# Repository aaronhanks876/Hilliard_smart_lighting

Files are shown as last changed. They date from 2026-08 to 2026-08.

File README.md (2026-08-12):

# Hilliard Smart Lighting 
   
## Rasperry PI IP address:
192.168.60.6
## MQTT Usernames and Passwords
### RGB boxes:
n = the number of the box   
Username: RGBn  
Password: HilliardRGB#n
### AC boxes:
Username: ACn  
Password: HilliardAC#n
### Node-RED Broker
Username: Node-RED  
Password: HilliardNode-RED
### Music Processing
Username: MusicBox  
Password: HilliardMusicBox

## Other Usernames and Passwords
### Node-RED Admin Account
Username: intern  
Password: Nut-3nact-D3pict!
### Node-RED UI/User Account
Username: Hilliard  
Password: Sm3lls-Lik3-Sad!

# System Explanation  
Written here is a brief explanation of the flow of the system, followed by more in depth explanations of each individual part of the system.
The system works in 4 major steps:
1. Audio is played on a computer with a pyapp installed to run the music processing. The app reads the system audio and runs a fast fourier transform to seperate the audio into frequencies. The app can then analyze different frequency ranges (bass, treble, and mid) and send out a trigger when they cross a certain threshold (80%, for example).
2. The trigger signal is sent to the MQTT broker, and is redirected to Node-RED, which runs the user interface for lighting control
3. A lighting control signal determined by configuration in the user interface is sent to the broker by Node-RED, and is redirected to the individual lighting boxes.
4. The individual boxes receive their instructions and flash accordingly
## Music Processing
## MQTT
MQTT is the protocol used for the sending of control signals in the reactive lighting system.
### Topics
The different parts of the system are organized into various topics:
| **/lights** | **/lights/RGB** | **/lights/RGB/boxn** | **/lights/RGB/boxn/connection** | **/lights/RGB/brightness** | **/lights/RGB/speed** |
| :---: | :---: | :---: | :---: | :---: | :---: |
| Where trigger signals from the music processing are sent | An organizational topic | Where the light controls for each individual RGB box (of number n) are sent | Where connection and disconnection messages from each individual RGB box (of number n) are sent | Where brightness controls for RGB boxes are sent | Where speed controls for RGB boxes are sent |
| | **/lights/AC**  | **/lights/AC/boxn**  | **/lights/AC/boxn/connection**  | | |
| | An organizational topic | Where the light controls for each individual AC box (of number n) are sent | where connection and disconnection messages from each individual AC box (of number n) are sent | | |

### Broker
The MQTT broker is run by Mosquitto on a Raspberry PI 
### Node-RED
Node-RED provides configuration of the lights. It runs the user interface, which is hosted by a Raspberry PI alongside the code itself. The code menu can be accessed by entering the ip of the Raspberry PI alongside the 1880 port into the search bar: "(IP address):1880". The UI can be accessed by typing in the same address alongside "/ui": "(IP address):1880/ui"  
  
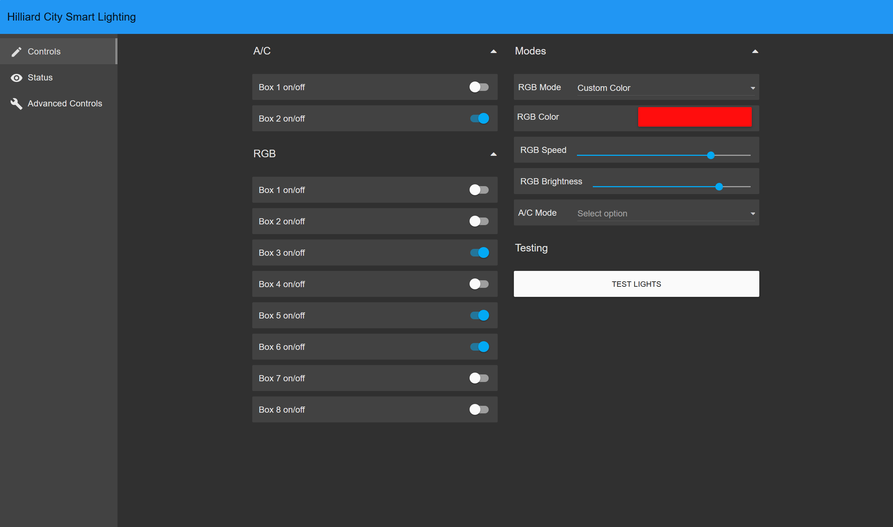
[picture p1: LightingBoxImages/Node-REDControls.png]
  
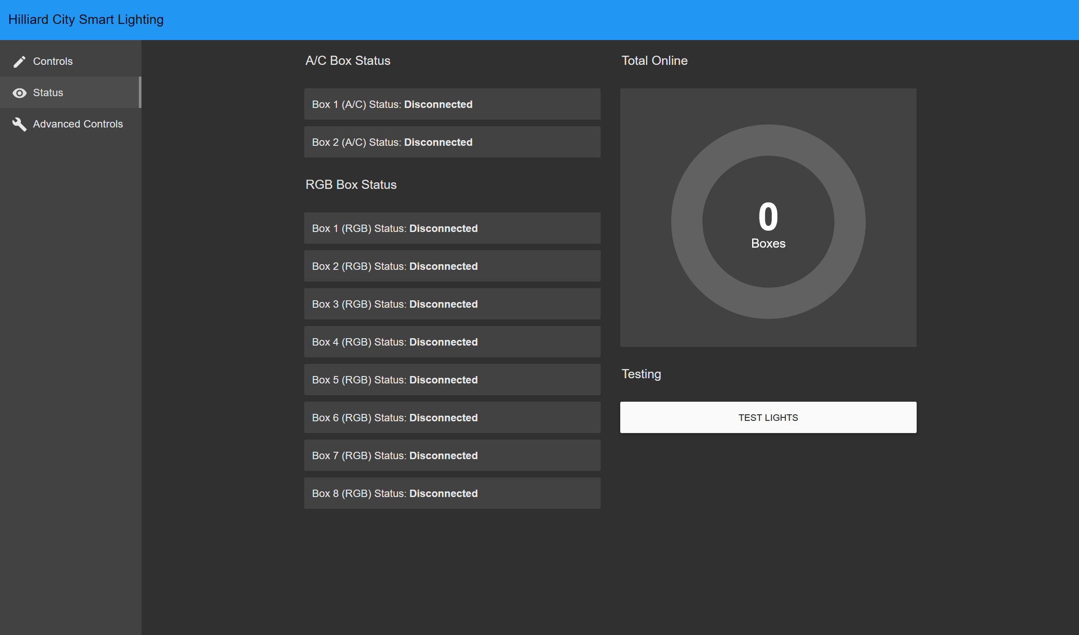
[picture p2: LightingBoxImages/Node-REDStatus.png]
  
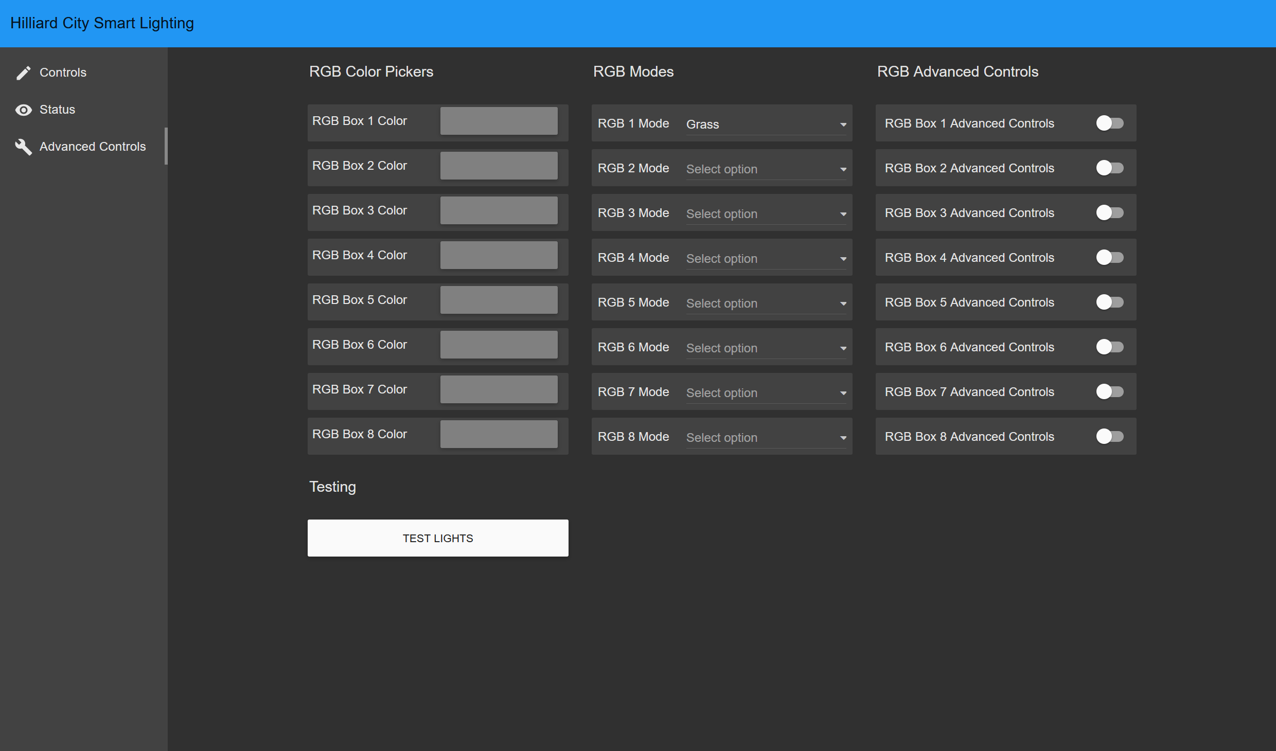
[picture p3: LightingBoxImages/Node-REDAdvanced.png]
  

#### Code Explanation
##### Overview
The Node-RED code works by receiving some input signal from the MQTT broker, sequentially checking all of the settings configured in the UI, and outputting the appropriate signal to send to the boxes. 
##### User Interface
The UI is built using the UIBUILDER Node-RED addon. Through these nodes the different options in the UI are configured. This includes the on/off toggles for all the boxes, the advanced mode toggles for the RGB boxes, the HSV color pickers, the mode selectors for all the boxes, the speed and brightness sliders for the RGB boxes, the test lights buttons, and the total boxes online display.
##### RGB 
- The bulk of the RGB code is checking the settings to see what should be sent to the different boxes. It works in eight phases to check for all of the settings:
  1. The code receives a trigger from an MQTT node (the contents of the signal do not matter)
  2. The code sets a variable "time" to the current UNIX time
  3. The code sets a "delayTime" variable to the sum of "time," and a "delay" variable. It then sets the message payload to a string of "mode " + delayTime.
  4. The message is sent to eight different switches (for eight different boxes), all of which check if their assigned box is turned on. 
  5. The message is sent through a switch which checks if advanced mode is turned on for the assigned box. It then sends the messages to either the regular mode, or advanced mode switches.
  6. Both regular and advanced mode switches check if the mode is set to custom. They then send to either the mode changer, or the custom color changer for their respective complexity.
  7. Both changers will change the "mode" part of the message payload into the mode set in the UI. The color changer will send an HSV value, and the mode will send a value from 1-5. If this is the advanced mode, it will be specific to that box. If it is regular mode, it will be the generalized mode.
  8. The resulting messages payload is sent to an MQTT node which publishes to the proper topic for their respective box.
- The RGB speed and brightness sliders both send the result directly onto their respective topics, which are read by the RGB boxes.
- The RGB connection works by setting the connection status when a given box sends a connection or disconnection message. 
##### AC
- The AC code is far simpler than the RGB code, because it does not have advanced controls to control the individual boxes. It works in five phases instead of eight.
  1. The code receives a trigger from an MQTT node (the contents of the signal do not matter)
  2. The trigger is sent to two different switches (one for each box), each of which checks if its assigned box is on
  3. The trigger is sent through a change node, and is changed into the number for the mode set in the UI
  4. The message is sent through a delay node, which delays it so that it will be in sync with the RGB boxes
  5. The message is sent to an MQTT node which publishes to the proper topic for its assigned box
- AC connection status works in the same way as RGB connection status
##### Broker
- The connection display works by giving each box a number variable for its connection. If it is connected, then it is a one, and if it is not connected, then it is a 0. All these variable are summed and displayed in a gauge in the user interface
- Test lights buttons work by using an MQTT node to send a signal to the same topic the music processing code sends signals on.
  
#### List of Utilities
- Controls
  - A/C
    - On/off control for A/C boxes
  - Modes
    - RGB Mode
      - Fire
      - Grass
      - Ocean
      - Rainbow
      - Christmas
      - Custom
    - RGB Color
      - A color picker, used alongside the "Custom" RGB mode to allow for the user to pick a custom color
    - RGB Speed
      - Used to choose the speed at which the RGB pulses travel
    - RGB Brightness
      - Used to choose the brightness of the RGB LEDs
    - A/C Mode
      - Twinkle
      - Flash
  - RGB
    - On/off control of RGB boxes
  - Testing
    - Has a button to send a test signal to the lights
- Status
  - A/C Box Status
    - Shows the connection status of all A/C boxes
  - RGB Box Status
    - Shows the connection status of all RGB boxes
  - Total Online
    - Has a dial that shows the amount of boxes that are online
  - Testing
    - Has a button to send a test signal to the lights
- Advanced Controls
  - RGB Color Pickers
    - HSV color pickers for each individual box
  - RGB Modes
    - Mode selectors for each individual box
  - RGB Advanced Controls
    - Toggles to turn on or off advanced controls for each individual box
  - Testing
    - Has a button to send a test signal to the lights
  
## RGB Lighting Control Boxes  
The RGB lighting control boxes (RGB boxes) are stored inside waterproof boxes, and comprised of one ESP32 microcontroller to run the code, a 5V power supply to power the ESP32, and an RGB connection cable.  
  
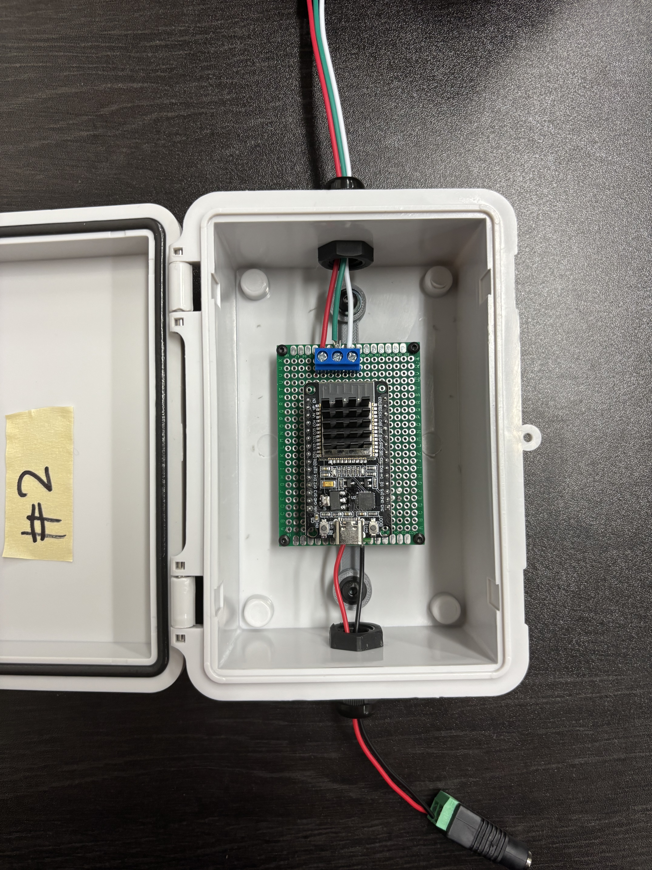
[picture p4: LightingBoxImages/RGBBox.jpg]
  

### ESP32 Code explanation

`setup()`
- Checks to see what protocol the lights follow (RGB or GRB)
- Calculates the center and end points (collision distances) of each pulse
- Sets all the LEDs to black
- Runs `connectToWifi()`
- Sets up the MQTT connection
- Syncs up the ESP's internal clock with time from pool.ntp.org.

`loop()` 
- Tries to reconnect to the server if the connection is lost
- Loops through mqtt_client_loop()
- Runs through `processDelays()` to push through the backlog
- Checks to see if the LEDs need to be updated based on the system clock.

`updateAnimations() `
- Runs the pulses, pushing the lit LED outwards until the collision distance

`drawPatterns()`
- Defines what each of the `colorModes` do (how they fade/change over the strip)

`spawnPulse()`
- Loops through all of `pulsePositions[]` and sets those that are equal to -1 (inactive) to the `targetColor`

`setLedSafe()` 
- Sets LEDs, but only when they actually exist, preventing errors

`Get_Epoch_Time` 
- Requests the current time from the internet to the second

`mqttCallback()` 
- Handles the incoming messages, and adds them to the backlog with their timestamp

`handleModeMessage()` 
- Adds triggers and delays to the backlog arrays in indexes 0-4, overwriting the beginning of the arrays if it runs out of space

`processDelays()`
- Loops though all 5 elements of the `triggerBacklog` (the array holding the modes for signals), skipping elements that are equal to -1 (empty)
- Checks the `delayBacklog` (the array holding the time of execution for signals) of elements that are not equal to -1 with `currentMillis` (the current time), triggering the lights if the difference of their last 3 digits is less than the threshold (100), and removing the element from the backlog arrays

`handleSpeedMessage()`
- Updates the speed with a scaled number received from MQTT

`handleBrightnessMessage()`
- Updates the brightness

`connectToWifi()`
- Loops until the network is connected, then prints "Connected to the WiFi network"

`connectToMQTTBroker()`
- Loops until the broker is connected
- Sets the "death message" to "Disconnected"
- Subscribes to topics 
- Publishes the "Connected" message

## A/C Lighting Control Boxes
The A/C lighting control boxes (A/C boxes) are designed to have six outlets to connect to one large Christmas tree. They are comprised of one ESP8266 microcontroller, three programmable A/C PWM dimmers, one 5V power supply, and six outlets. The ESP8266 controls the three dimmers, each of which outputs the controlled power to two outlets.  

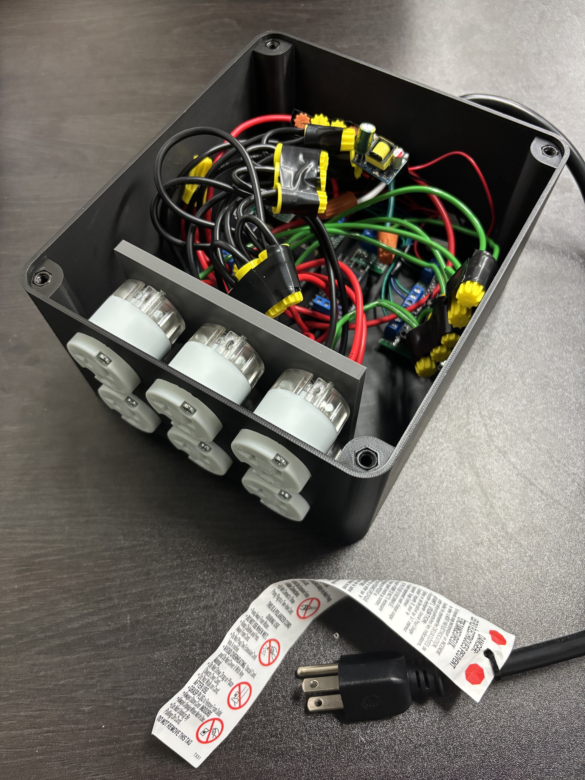
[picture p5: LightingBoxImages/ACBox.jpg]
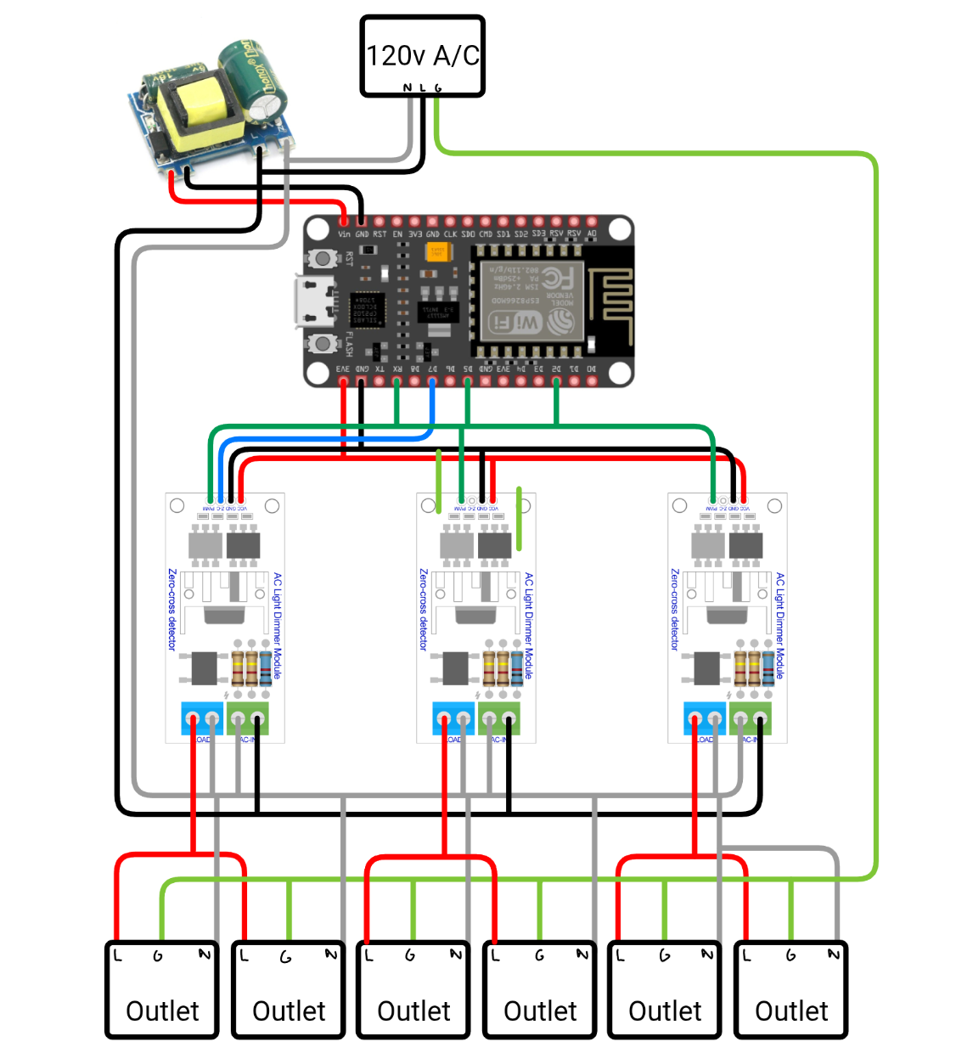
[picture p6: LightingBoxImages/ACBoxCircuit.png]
 

### ESP8266 Code Explanation

`setup()`
- Initializes three `dimmerLamp` objects, each of which corresponds to a physical dimmer
- Runs `connectToWifi()`
- Sets up the MQTT connection over three functions

`connectToWifi()` 
- Loops until the network is connected, then prints "Connected to the WiFi network".

`connectToMQTTBroker()` 
- Loops until the broker is connected
- Sets the "death message" to "Disconnected"
- Subscribes to topics 
- Publishes the "Connected" message

`mqttCallback()` 
- Handles the incoming messages, and activates the proper mode function based on the number sent 

`mode1()`
- Rapidly raises the brightness to 100 then lowers it to the variable `twinkleMap` (set to 55), making the lights "twinkle."

`mode2()` 
- Rapidly raises the brightness to 100 then lowers it to the variable `flashMap` (set to 30), making the lights "flash."

`loop()` 
- Tries to reconnect to the server if the connection is lost
- Loops through `mqtt_client_loop()`

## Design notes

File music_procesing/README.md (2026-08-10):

# Audio Reactive Lighting Trigger System

## Overview

This project analyzes an audio file in real time and detects musical events. When specific audio conditions are met, the program sends MQTT trigger messages to an external lighting controller.

The Python program is responsible for:

- Reading audio
- Analyzing frequency content
- Detecting musical events
- Sending MQTT triggers

The lighting controller is responsible for deciding what visual effect to run.

---

# System Flow

```
Audio File
    |
    v
Audio Stream
    |
    v
FFT Frequency Analysis
    |
    v
Audio Processing
    |
    v
Beat Detection
    |
    v
Trigger Detection
    |
    v
MQTT Message
    |
    v
Lighting Controller
```

---

# File Structure

```
music_processor/

├── main.py
├── config.py
│
├── audio_stream.py
├── analyzer.py
├── filters.py
├── beat_detector.py
├── broadcaster.py
│
└── README.md
```

---

# main.py

## Purpose

`main.py` controls the complete audio processing pipeline.

It initializes:

- MQTT connection
- Audio stream
- FFT analyzer
- Audio filters
- Beat detector
- MQTT broadcaster

The main loop continuously:

1. Receives an audio chunk
2. Analyzes frequency information
3. Processes audio levels
4. Detects beats
5. Sends triggers when events occur

---

# config.py

## Purpose

Stores all adjustable settings.

## Audio Settings

Example:

```python
WINDOW_SIZE = 2048
```

Controls the size of each audio analysis frame.

A larger window:

- More frequency accuracy
- More processing delay

A smaller window:

- Faster response
- Less frequency resolution

## MQTT Settings

Example:

```python
MQTT_BROKER = "192.168.60.6"
MQTT_PORT = 1883
```

Defines where trigger messages are sent.

---

# audio_stream.py

## Purpose

Handles loading and streaming the audio file.

Functions:

- Loads the audio file
- Converts stereo audio into a single channel
- Creates audio chunks
- Sends chunks to the analyzer
- Plays audio through the output device

The audio is split into small sections:

```
Full Song

|
|
v

Chunk 1
Chunk 2
Chunk 3
Chunk 4
```

Each chunk is analyzed individually.

---

# analyzer.py

## Purpose

Converts audio samples into frequency information using Fast Fourier Transform (FFT).

FFT converts the audio from:

```
Time Domain

Amplitude over time
```

into:

```
Frequency Domain

Energy at different frequencies
```

The analyzer separates audio into four frequency ranges.

---

# Frequency Bands

## Bass

```
40Hz - 180Hz
```

Detects:

- Kick drums
- Low bass frequencies

## Low Mid

```
180Hz - 600Hz
```

Detects:

- Lower instruments
- Body of sounds

## Mid

```
600Hz - 3000Hz
```

Detects:

- Vocals
- Main instruments

## Treble

```
3000Hz - 10000Hz
```

Detects:

- Cymbals
- High frequency sounds

---

# filters.py

## Purpose

Processes frequency levels so they can be used for event detection.

It contains:

## Adaptive Gain

Automatically adjusts sensitivity based on the current audio level.

This allows the system to respond to different songs without manually changing thresholds.

---

## Smoothing

Reduces rapid changes in values.

Example:

```
Raw:

20
90
30
100

Smoothed:

45
65
55
75
```

---

## Peak Hold

Keeps strong audio events active briefly.

This allows short sounds like drum hits to be detected more reliably.

---

## Brightness Mapper

Converts processed audio values into a 0-100 range.

Example:

```
Input:

0.75

Output:

75
```

---

# beat_detector.py

## Purpose

Detects sudden changes in audio energy.

It uses spectral flux.

Spectral flux measures how much the frequency spectrum changes between audio frames.

Process:

```
Current Spectrum

        +

Previous Spectrum

        |

        v

Difference Calculation

        |

        v

Beat Strength
```

When the change exceeds the detection threshold:

```
Beat Detected = True
```

---

# broadcaster.py

## Purpose

Sends detected audio events to the lighting controller.

The broadcaster does not control lighting effects.

It only sends MQTT trigger messages.

---

# Trigger Detection

The system checks:

## Bass Events

If bass energy crosses the trigger threshold:

```
bass > threshold
```

a bass trigger is sent.

---

## Beat Events

If the beat detector identifies a strong audio change:

```
beat_strength > threshold
```

a beat trigger is sent.

---

## Treble Events

If high frequency energy crosses the threshold:

```
treble > threshold
```

a treble trigger is sent.

---

# MQTT Output

The Python program sends messages through MQTT.

Topic:

```
lights
```

Example messages:

```
bass
```

```
beat
```

```
treble
```

The receiving controller interprets these messages and runs the appropriate lighting pattern.

---

# Trigger Protection

The system includes two methods to prevent excessive triggers.

## Rising Edge Detection

A trigger occurs only when the signal crosses above the threshold.

Example:

```
Audio Level:

40
60
85  <-- Trigger
90
80
70
```

Only the transition above the threshold creates an event.

---

## Cooldown Timer

After a trigger is sent, a short delay prevents repeated messages.

Example:

```
Beat

(wait)

Beat

(wait)

Beat
```

This keeps the output clean and prevents rapid repeated effects.

---

# Complete Data Flow

```
                Audio File

                    |

                    v

            audio_stream.py

                    |

                    v

             Audio Samples

                    |

                    v

              analyzer.py

                    |

                    v

        Frequency Band Energy

                    |

                    v

              filters.py

                    |

                    v

          Processed Audio Levels

                    |

          +---------+---------+

          |                   |

          v                   v

 beat_detector.py     Trigger Logic

          |                   |

          +---------+---------+

                    |

                    v

            broadcaster.py

                    |

                    v

                 MQTT

                    |

                    v

          Lighting Controller
```

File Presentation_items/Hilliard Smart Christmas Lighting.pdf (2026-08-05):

Tony Brown, Aaron Hanks,

## Yash Patel

# Hilliard Smart

| Christmas Lighting

- Smart Christmas Lighting for Hilliard is not a business idea
- We initially planned on building street lamps to prevent light

pollution
- We found issues in the research process, and abandoned the project
- We were told about a separate project related to lighting
- What is “reactive lighting”

# How did we get here?

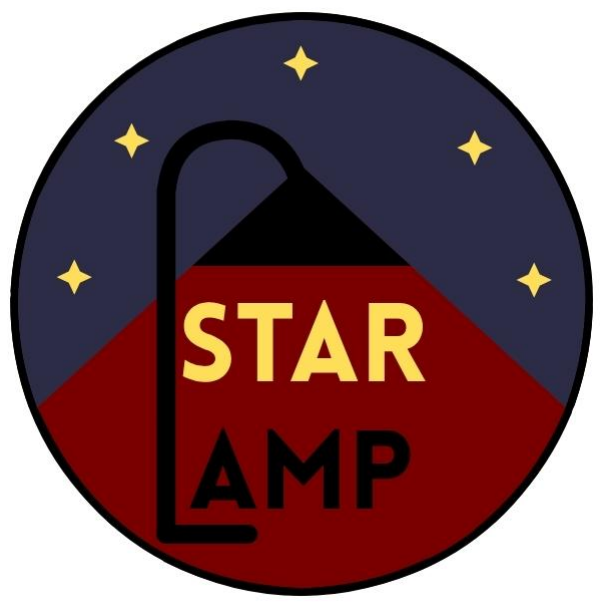
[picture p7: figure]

Our original Idea

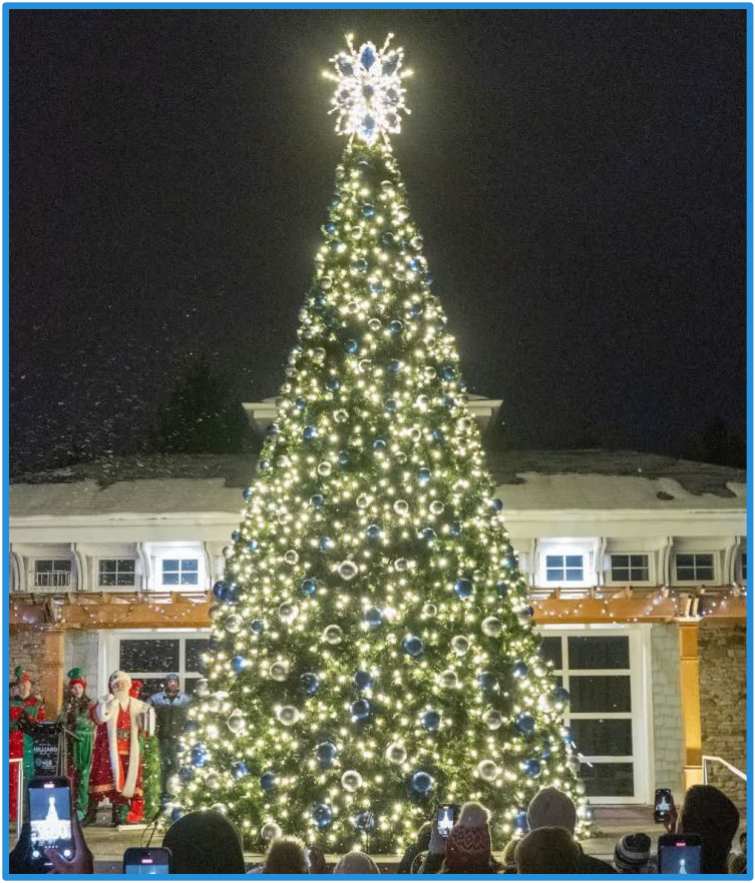
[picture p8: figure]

- The audio is collected and processed, sending signals in

sync with the music
- The signals are sent to a central server
- The server directs the signals to a controllable user

interface that determines specific instructions for the lights
- The system sends the light instructions to lighting boxes
- We control six smaller RGB lighting trees, and 1 large

regular lighting tree

# How does it work?

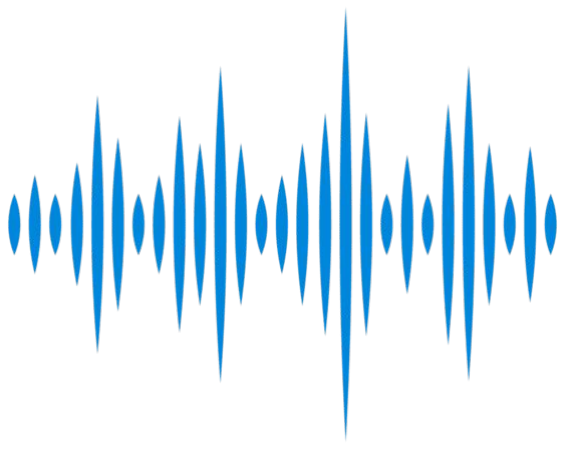
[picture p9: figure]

- Audio is played on a laptop while code is running in the

background listening
- The code takes a chunk of audio and separates it into frequency

ranges to use like bass, mid, and treble
- Those frequency ranges are put through filters to isolate

characteristics of the audio
- The code sends a triggers to the central server based on the

music

# Audio Input & processing

## The system to process the audio so that the individual lighting units react to the music

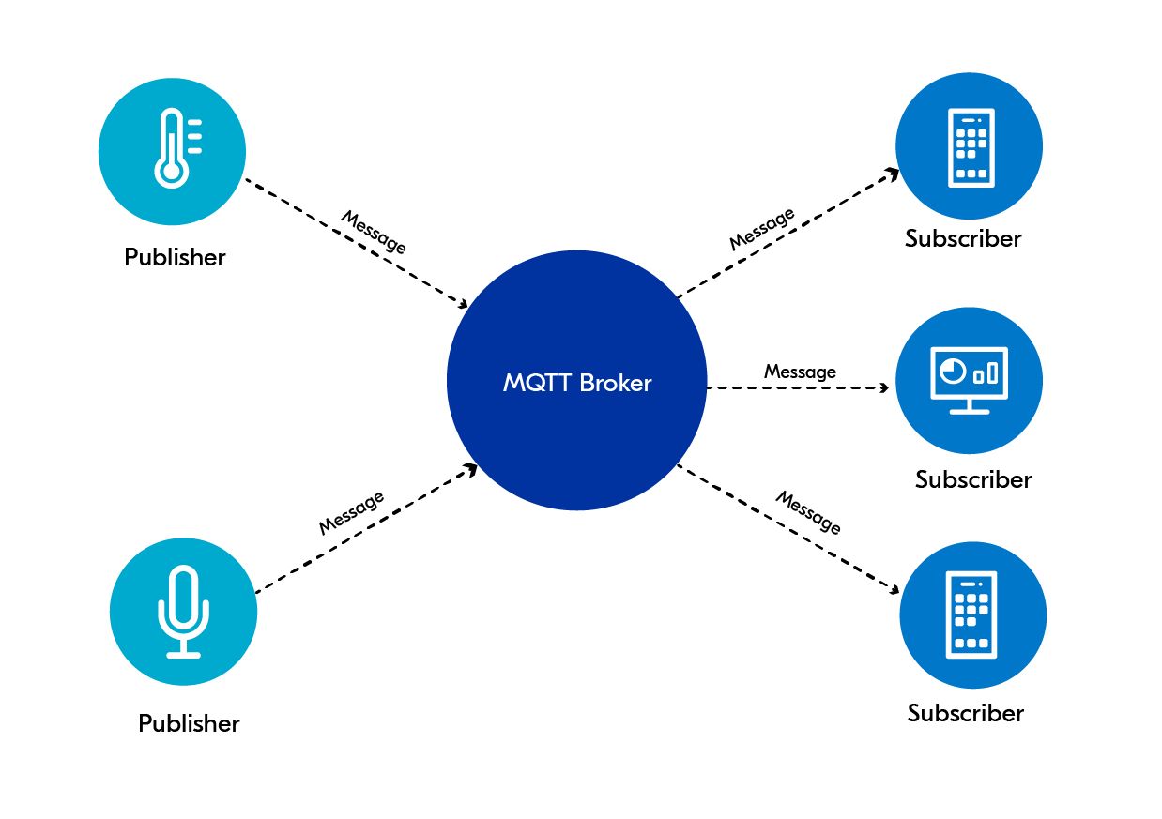
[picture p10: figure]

- The system runs on MQTT communication

protocol (broker & clients)
- The broker is run on a Raspberry Pi
- Each box is assigned 2 unique topics, one for

connection status and one lighting signals
- There are usernames and passwords for each part

of the system

# Central Server

## The system to manage data flow and sync light displays

# Node-red

## An interactive user interface that

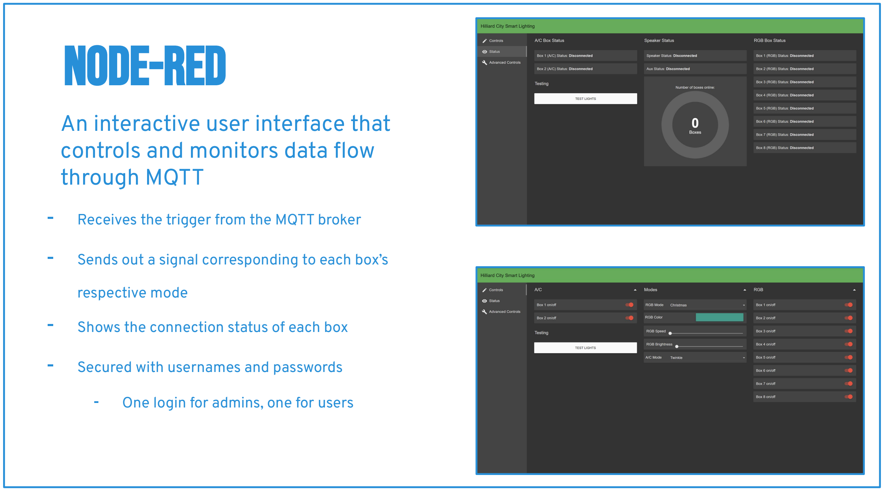
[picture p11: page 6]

- Receives the trigger from the MQTT broker
- Sends out a signal corresponding to each box’s

respective mode
- Shows the connection status of each box
- Secured with usernames and passwords
- One login for admins, one for users

## controls and monitors data flow through MQTT

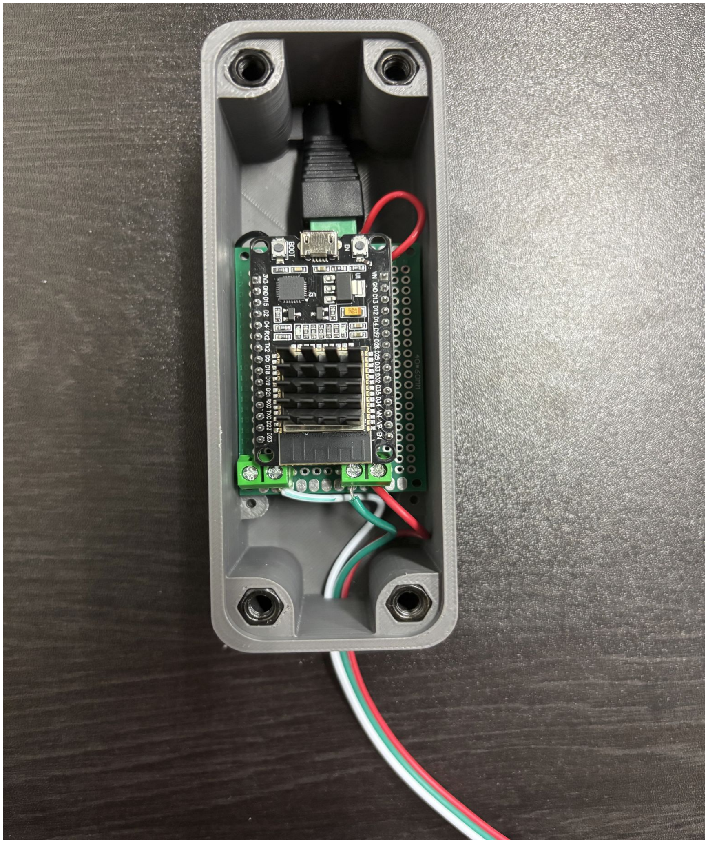
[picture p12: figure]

- What is RGB?

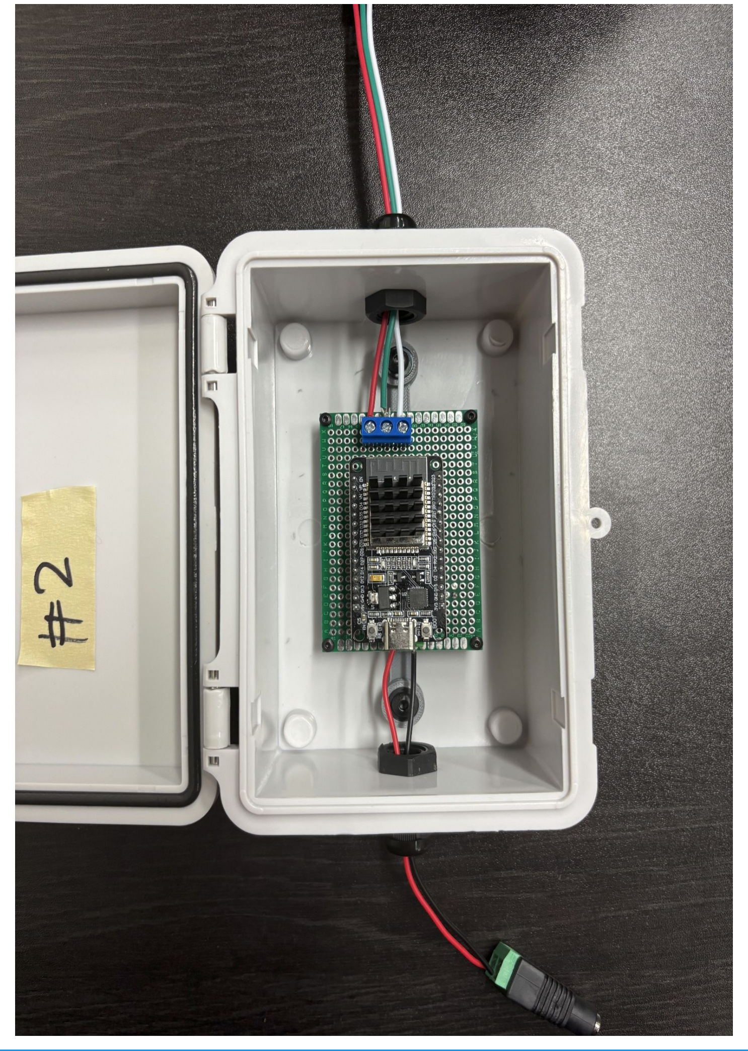
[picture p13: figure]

- Uses a microcontroller (ESP32) to connect to the server
- Currently designed to work with 200 leds (66 feet) of

RGB leds
- Weatherproof design
- We have made 8 of them to be implemented into Old

Hilliard

# RGB lighting unit

## The device controlling lights at each tree

# REgular lighting boxes

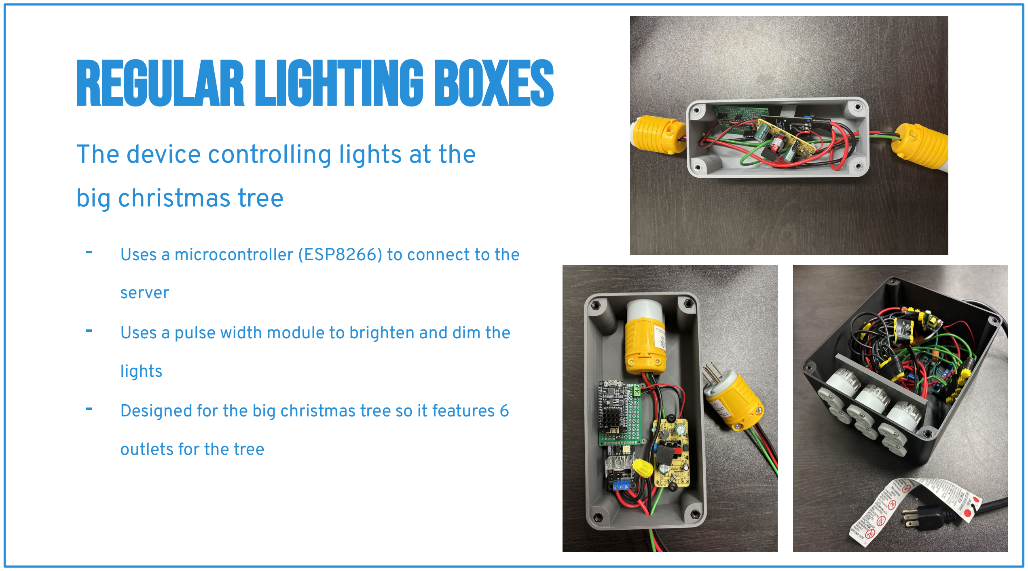
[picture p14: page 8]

- Uses a microcontroller (ESP8266) to connect to the

server
- Uses a pulse width module to brighten and dim the

lights
- Designed for the big christmas tree so it features 6

outlets for the tree

## The device controlling lights at the big christmas tree

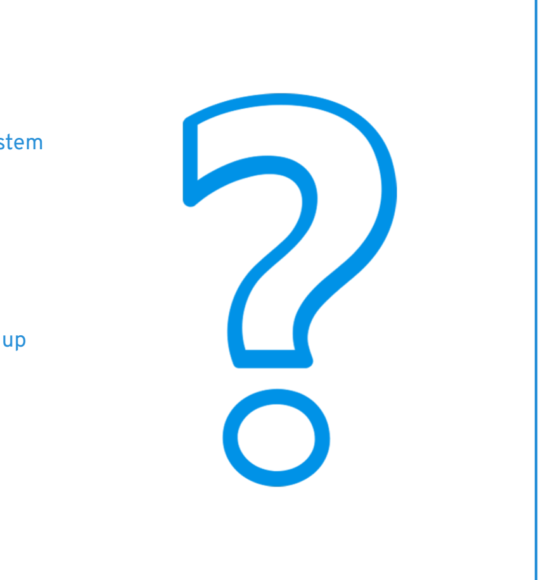
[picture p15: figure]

- We will continue working until we finish development of the system
- Decreasing delay
- Better user interface for music processing
- More power for longer RGB strings
- We will set up the system in Hilliard when Christmas is coming up
- Connecting the system to Wifi
- Configuring the system to the existing lights
- Setting up a computer to run the music processing

# Future plans

# THank you!

## Contact the HSCL team:

tony.auron.brown@gmail.com aaronhanks876@gmail.com
yashpateleight@gmail.com

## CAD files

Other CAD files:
Fusion_models/AC_Box/AC Box Outlet Connector Insert.f3d
Fusion_models/AC_Box/AC Box and Lid.f3d
Fusion_models/RGB Box and Lid v1.f3d
Fusion_models/Waterproof box inset.f3d

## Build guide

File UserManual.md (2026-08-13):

# User Manual
## Introduction
The following manual contains instructions for the setup, usage, and proper maintenance of the Hilliard Smart Christmas Lighting system. 
## Setup
To properly set up the smart lighting system, the following steps must be follow sequentially. If they are done out of order, errors in the function of the system could arise.
1. Plug the Raspberry PI into the wall
   - This must be done for the elements of the system to communicate, and to be able to access the user interface
2. Download the Hilliard Smart Lighting app on any computer with a USB-C port. Plug in the computer or laptop so that the app can run without interruption.
3. Plug in the lighting boxes, and plug in any RGB lights or wall lights into their respective boxes
4. Open the Hilliard Smart Lighting app and press the "Start listening" button
5. Plug in any music playing device to the computer via an aux cord, and plug in any speakers via the USB port (a USB to aux cord may be necessary)
6. Play music
   - At this point the music should play through the speakers, but the lights may not be reacting accordingly
8. Open the following URL: (IP HERE):1880/ui
9. Log in with the credentials
10. Configure all settings
    - When the Raspberry PI is first powered on, all of the settings must be set to something or else the lights might not work. Though it appears that they are set to something, they are not until they have been pressed
    - The lighting boxes may not work until all their settings are set to something

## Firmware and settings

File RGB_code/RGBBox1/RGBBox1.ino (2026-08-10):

#include <FastLED.h>
#include <WiFi.h> 
#include <PubSubClient.h>
#include "time.h"
#include <ESP32Time.h>
#include "millisDelay.h"


// ==========================================
// 1. SYSTEM CONFIGURATION & HARDWARE SETTINGS
// ==========================================
#define NUM_LEDS 100           // Total physical LED count
#define LEDS_PER_SEGMENT 10      // Desired number of LEDs per segment
#define DATA_PIN 4                // Pin output to LED strip data line

// Non-blocking Animation Limits
#define MAX_PULSES 15            // Maximum simultaneous tracked active pulses

// Network Credentials
const char* ssid = "HCL Interns";
const char* password = "Interns123!";

// MQTT Broker Settings
const char *mqtt_broker   = "192.168.60.6"; 
const int   mqtt_port     = 1883;           
const char *mqtt_username = "RGB1"; //Change with box #        
const char *mqtt_password = "HilliardRGB#1"; //Change with box #   

// Topic Subscriptions
const char *mqtt_topic        = "lights/RGB/box1"; //Change with box #   
const char *speed_topic       = "lights/RGB/speed";
const char *brightness_topic  = "lights/RGB/brightness";
const char *will_topic        = "lights/RGB/box1/connection"; //Change with box #   

// Time Stuffs
ESP32Time rtc(0);
const char* ntpServer = "pool.ntp.org";
unsigned long Epoch_Time; 
unsigned long New_Epoch_Time;

String delayBacklog[] = {"-1", "-1", "-1", "-1", "-1"};
String triggerBacklog[] = {"-1", "-1", "-1", "-1", "-1"};
int backlogCount = 0;
int executeCount = 0;

bool invertRedGreen = true; //switch red and green (seed lights)
//bool invertRedGreen = false; //(LED strip lights)

int customColor[3];

// ==========================================
// 2. COMPILE-TIME AUTOMATIC SAFETY MATH
// ==========================================
#define NUM_CENTERS       (NUM_LEDS / LEDS_PER_SEGMENT) 
#define LEFTOVER_LEDS     (NUM_LEDS % LEDS_PER_SEGMENT)






// ==========================================
// 3. GLOBAL VARIABLES & STATE TRACKING
// ==========================================
CRGB leds[NUM_LEDS];
int centers[NUM_CENTERS];         
int collisionDistance = 0;        
unsigned long lastFrameTime = 0;


int ledSpeed = 15;                // Tracks your animation timing frame window
int currentBrightness = 50;      // Tracks dynamic strip intensity limits

// Pulse Tracking Parallel Arrays
int pulsePositions[MAX_PULSES];
CRGB pulseColors[MAX_PULSES]; 

// Network Client Global Objects
WiFiClient espClient;
PubSubClient mqtt_client(espClient);

// Forward Declarations
void connectToWiFi();
void connectToMQTTBroker();
void mqttCallback(char *topic, byte *payload, unsigned int length);
void handleModeMessage(String message);
void handleSpeedMessage(String message);
void handleBrightnessMessage(String message);
void spawnPulse(CRGB targetColor);
void setLedSafe(int index, CRGB color);
void drawPatterns(int pulseIndex, int distance);
void updateAnimations();






// ==========================================
// 4. MAIN SETUP AND INITIALIZATION
// ==========================================
void setup() {
  Serial.begin(9600);
  
  // FastLED Setup
  if (invertRedGreen){ // inverted RGB setup
     FastLED.addLeds<WS2812B, DATA_PIN, RGB>(leds, NUM_LEDS).setCorrection(TypicalLEDStrip);
  }
  else{ //origional RGB setup
    FastLED.addLeds<WS2812B, DATA_PIN, GRB>(leds, NUM_LEDS).setCorrection(TypicalLEDStrip); 
  }
  FastLED.setBrightness(currentBrightness);
  FastLED.clear();
  FastLED.show();

  // Run Calculations and Spacing Setup
  collisionDistance = LEDS_PER_SEGMENT / 2 + 1;
  for (int i = 0; i < NUM_CENTERS; i++) {
    centers[i] = (LEDS_PER_SEGMENT * i) + (LEDS_PER_SEGMENT / 2);
  }

  // Initialize all tracking animation slots to inactive
  for (int i = 0; i < MAX_PULSES; i++) {
    pulsePositions[i] = -1;
    pulseColors[i] = CRGB::Black;
  }

  // Network Provisioning
  connectToWiFi();
  mqtt_client.setServer(mqtt_broker, mqtt_port);
  mqtt_client.setCallback(mqttCallback); // Pointing library to unified routing gate
  connectToMQTTBroker();
  // Time syncing
  configTime(0, 0, ntpServer);
  Epoch_Time = Get_Epoch_Time() + 1; 
  New_Epoch_Time = Get_Epoch_Time();
  while (New_Epoch_Time != Epoch_Time){//breaks the loop when the second "ticks over"
    delay(1);
    New_Epoch_Time = Get_Epoch_Time();
  }
  Serial.println("Time set");
  rtc.setTime(New_Epoch_Time);
  Serial.println("Setup Complete");
}






// ==========================================
// 5. MAIN CORE EXECUTION LOOP
// ==========================================
void loop() {
  if (!mqtt_client.connected()) {
    connectToWiFi(); 
    connectToMQTTBroker();
  }
  mqtt_client.loop(); 
  processDelays();
  unsigned long currentTime = millis();
  if (currentTime - lastFrameTime >= (unsigned long)ledSpeed) {
    lastFrameTime = currentTime;
    updateAnimations();
  }
}






// ==========================================
// 6. ANIMATION ENGINE & PATTERN RECTIFIERS
// ==========================================
void updateAnimations() {
  fadeToBlackBy(leds, NUM_LEDS, 50); 

  for (int i = 0; i < MAX_PULSES; i++) {
    int dist = pulsePositions[i];
    if (dist == -1) continue; 

    drawPatterns(i, dist);
    pulsePositions[i]++;

    if (pulsePositions[i] >= collisionDistance) {
      pulsePositions[i] = -1; 
    }
  }
  FastLED.show();
}

void drawPatterns(int pulseIndex, int distance) {
  CRGB drawColor = pulseColors[pulseIndex];

  for (int c = 0; c < NUM_CENTERS; c++) {
    int centerPos = centers[c];
    /*New Color Template (also update handleModeMessage and node-RED)
    else if (drawColor == CRGB::[color]) {
      CRGB [color]Color = CHSV(hue, saturation , random8(200, 255));
      setLedSafe(centerPos + distance, [color]Color);
      setLedSafe(centerPos - distance, [color]Color);
    }*/ 
    if (drawColor == CRGB(0,0,0)) {
      uint8_t hue = distance * 8; 
      CRGB rainbowColor = CHSV(hue, 255, 255);
      setLedSafe(centerPos + distance, rainbowColor);
      setLedSafe(centerPos - distance, rainbowColor);
    } 
    else if (drawColor == CRGB(255,255,255)) {
      CRGB rightColor = (distance % 2 == 0) ? CRGB::Red : CRGB::Lime;
      CRGB leftColor  = (distance % 2 == 0) ? CRGB::Lime : CRGB::Red;
      setLedSafe(centerPos + distance, rightColor);
      setLedSafe(centerPos - distance, leftColor);
    } 
    else if (drawColor == CRGB::BlueViolet) {
      uint8_t oceanHue = 130 + (distance % 4) * 10; 
      CRGB oceanColor = CHSV(oceanHue, 240, 255);
      setLedSafe(centerPos + distance, oceanColor);
      setLedSafe(centerPos - distance, oceanColor);
    } 
    else if (drawColor == CRGB::DarkOrange) {
      CRGB fireColor = CHSV(random8(0, 32), 255, random8(180, 255));
      setLedSafe(centerPos + distance, fireColor);
      setLedSafe(centerPos - distance, fireColor);
    } 
    else if (drawColor == CRGB::DarkGreen) {
      CRGB grassColor = CHSV(64 + (distance % 4) * 8, 255, random8(200, 255));
      setLedSafe(centerPos + distance, grassColor);
      setLedSafe(centerPos - distance, grassColor);
    } 
    else if (drawColor == CRGB::HotPink) {
      CRGB pinkColor = CHSV(230, 255 , random8(200, 255));
      setLedSafe(centerPos + distance, pinkColor);
      setLedSafe(centerPos - distance, pinkColor);
    } 
    else if (drawColor == CRGB::LightBlue) {
      CRGB lBlueColor = CHSV(127, 255 , random8(200, 255));
      setLedSafe(centerPos + distance, lBlueColor);
      setLedSafe(centerPos - distance, lBlueColor);
    } 
    
    else if (drawColor == CRGB::Brown) { //custom color (brown is placeholder)
      CRGB customColorRGB = CHSV(customColor[0], customColor[1], customColor[2]);
      setLedSafe(centerPos + distance, customColorRGB);
      setLedSafe(centerPos - distance, customColorRGB);
    }
    else {
      setLedSafe(centerPos + distance, drawColor);
      setLedSafe(centerPos - distance, drawColor);
    }
  }
}

void spawnPulse(CRGB targetColor) {
  for (int i = 0; i < MAX_PULSES; i++) {
    if (pulsePositions[i] == -1) {
      pulsePositions[i] = 0; 
      pulseColors[i] = targetColor; 
      return;
    }
  }
}

void setLedSafe(int index, CRGB color) {
  if (index >= 0 && index < NUM_LEDS) {
    leds[index] = color;
  }
}






// ==========================================
// 7. NETWORK & COMMUNICATIONS PROTOCOLS
// ==========================================

unsigned long Get_Epoch_Time() {
  time_t now;
  struct tm timeinfo;
  if (!getLocalTime(&timeinfo)) {
    return(0);
  }
  time(&now);
  return now;
}


// UNIFIED HANDLER: Receives ALL topic payloads and filters them by string matching
void mqttCallback(char *topic, byte *payload, unsigned int length) {
  String message;
  for (unsigned int i = 0; i < length; i++) {
    message += (char) payload[i]; 
  }

  String topicStr = String(topic);

  if (topicStr == mqtt_topic) {
    handleModeMessage(message);
  } 
  else if (topicStr == speed_topic) {
    handleSpeedMessage(message);
  } 
  else if (topicStr == brightness_topic) {
    handleBrightnessMessage(message);
  }
}


void handleModeMessage(String message) {
  int delayMs = message.substring(message.length() - 5).toInt();  
  delayBacklog[backlogCount] = delayMs;
  triggerBacklog[backlogCount] = message;
  backlogCount ++;
  if(backlogCount == 5){
    backlogCount = 0;
  }
}

void processDelays(){
  for (int i = 0; i < 5; i ++){
    if (triggerBacklog[i].equals("-1")){
      continue;
    }
    unsigned long currentMillis = rtc.getMillis();
    if (abs(delayBacklog[i].toInt() - currentMillis) % 1000 < 50){
      if (triggerBacklog[i].substring(0, 1) == "1")       spawnPulse(CRGB::DarkOrange);
      else if (triggerBacklog[i].substring(0, 1) == "2")  spawnPulse(CRGB::DarkGreen);
      else if (triggerBacklog[i].substring(0, 1) == "3")  spawnPulse(CRGB::BlueViolet);
      else if (triggerBacklog[i].substring(0, 1) == "4")  spawnPulse(CRGB::Black); 
      else if (triggerBacklog[i].substring(0, 1) == "5")  spawnPulse(CRGB::White);
      else if (triggerBacklog[i].substring(0, 3) = "{\"h"){ //inputting custom colors from node-RED in this format: {"h":205.20000000000002,"s":49,"v":100}
        String shortenedMessage = triggerBacklog[i].substring(5);
        int firstCommaIndex = shortenedMessage.indexOf(",");
        customColor[0] = shortenedMessage.substring(0, firstCommaIndex).toInt() * 255 / 360;
        shortenedMessage = shortenedMessage.substring(firstCommaIndex + 5);
        int secondCommaIndex = shortenedMessage.indexOf(",");
        customColor[1] = shortenedMessage.substring(0, secondCommaIndex).toInt() * 255 / 100;
        customColor[2] = shortenedMessage.substring(secondCommaIndex + 5, shortenedMessage.length() - 1).toInt() * 255 / 100;
        spawnPulse(CRGB::Brown); //temporary color that we WILL NOT USE for anything else (it crashes the ESP if we dont do this)
      }
      triggerBacklog[i] = "-1";
      delayBacklog[i] = "-1";
    }
    delay(1);
  }
}

void handleSpeedMessage(String message) {
  int parsedSpeed = message.toInt(); // Fixed: safely parses numeric text value strings
  parsedSpeed = 50 - parsedSpeed / 2;
  ledSpeed = parsedSpeed;
}


void handleBrightnessMessage(String message) {
  int parsedBrightness = message.toInt();
  if (parsedBrightness >= 0 && parsedBrightness <= 100) {
    currentBrightness = parsedBrightness;
    FastLED.setBrightness(currentBrightness); // Refreshes global hardware matrix registers
  }
}


void connectToWiFi() {
  if (WiFi.status() == WL_CONNECTED) return;
  WiFi.begin(ssid, password);
  while (WiFi.status() != WL_CONNECTED) {
    delay(500);
  }
  Serial.println("WiFi Infrastructure Link Established.");
}


void connectToMQTTBroker() {
  while (!mqtt_client.connected()) {
    String client_id = "esp32-client-" + String(WiFi.macAddress());
    
    if (mqtt_client.connect(client_id.c_str(), mqtt_username, mqtt_password, will_topic, 2, true, "Disconnected" )) {
      Serial.println("MQTT Connection Handshake Complete.");
      mqtt_client.subscribe(mqtt_topic); 
      mqtt_client.subscribe(speed_topic); 
      mqtt_client.subscribe(brightness_topic); 
      mqtt_client.publish(will_topic, "Connected");
    } else {
      delay(5000);
    }
  }
}

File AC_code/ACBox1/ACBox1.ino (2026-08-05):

#include <ESP8266WiFi.h>
#include <PubSubClient.h>

#include <RBDdimmer.h>

#define zerocross  13  //D7
//PWM 1
#define outputPin1  3  //RX
//PWM 2
#define outputPin2  14 //D5
//Pwm 3
#define outputPin3  4  //D2

dimmerLamp dimmer1(outputPin1, zerocross);
dimmerLamp dimmer2(outputPin2, zerocross);
dimmerLamp dimmer3(outputPin3, zerocross);

int twinkleMap = 55;
int flashMap = 30;
int speed = 2;

// WiFi settings
const char *ssid = "HCL Interns";                     // WiFi name
const char *password = "Interns123!";                 // WiFi password

// MQTT Broker settings
const char *mqtt_broker = "192.168.60.6";             // MQRR broker IP
const char *mqtt_topic = "lights/AC/box1";            // Needs to be changed with box number
const char *will_topic = "lights/AC/box1/connection"; // Needs to be changed with box number

const char *mqtt_username = "AC1";                    // MQTT usernam
const char *mqtt_password = "HilliardAC#1";           // MQTT password
const int mqtt_port = 1883;                           // MQTT port

WiFiClient espClient;
PubSubClient mqtt_client(espClient);

void connectToWiFi();

void connectToMQTTBroker();

void mqttCallback(char *topic, byte *payload, unsigned int length);

void mode1();

void setup() {
    dimmer1.begin(NORMAL_MODE, ON);
    dimmer2.begin(NORMAL_MODE, ON);
    dimmer3.begin(NORMAL_MODE, ON);
    connectToWiFi();
    mqtt_client.setServer(mqtt_broker, mqtt_port);
    mqtt_client.setCallback(mqttCallback);
    connectToMQTTBroker();
}

void connectToWiFi() {
    WiFi.begin(ssid, password);
    while (WiFi.status() != WL_CONNECTED) {
        delay(500);
    }
    Serial.println("\nConnected to the WiFi network");
}

void connectToMQTTBroker() {
    while (!mqtt_client.connected()) {
        String client_id = "esp8266-client-" + String(WiFi.macAddress());
        if (mqtt_client.connect(client_id.c_str(), mqtt_username, mqtt_password, will_topic, 2, true, "Disconnected")) {
            mqtt_client.subscribe(mqtt_topic);
            mqtt_client.publish(will_topic, "Connected");
        } else {
            delay(2000);
        }
    }
}

void mqttCallback(char *topic, byte *payload, unsigned int length) {
    String message;
    for (int i = 0; i < length; i++) {
       message += (char)payload[i];
    }
    int intMessage = message.toInt();
    if (intMessage == 1){
        mode1();
    }
    else if (intMessage == 2){
        mode2();
    }
}

void mode1 (){ //Twinkle
	for (int i = twinkleMap; i < 100; i += speed){
		dimmer1.setPower(round(i));
        dimmer2.setPower(round(i));
        dimmer3.setPower(round(i));
	}
	for (int i = 100; i > twinkleMap; i -= speed){
		dimmer1.setPower(round(i));
        dimmer2.setPower(round(i));
        dimmer3.setPower(round(i));
	}
}

void mode2 (){ //Flash
	for (int i = flashMap; i < 100; i += speed){
		dimmer1.setPower(round(i));
        dimmer2.setPower(round(i));
        dimmer3.setPower(round(i));
	}
	for (int i = 100; i > flashMap; i -= speed){
		dimmer1.setPower(round(i));
        dimmer2.setPower(round(i));
        dimmer3.setPower(round(i));
	}
}


void loop() {
    if (!mqtt_client.connected()) {
        connectToMQTTBroker();
    }
    mqtt_client.loop();
}

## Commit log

2026-07-16 Add Raspberry Pi IP address to README
    Added the IP address for the sake of documentation
2026-07-16 Rename AC_code/MQTTscetchAC.ino to AC_code/MQTTsketchAC/MQTTsketchAC.ino
    Renamed for spelling and added a folder so that arduino IDE can run files with no errors
2026-07-16 Rename RGB_code/RGBThing.ino to RGB_code/RGBThing/RGBThing.ino
    Added folder so that Arduino IDE can run the file with no errors
2026-07-29 Add files via upload
    File that contains the insert for the waterproof box meant for the RGB protoboard
    [Waterproof box inset.f3d]
2026-07-29 Added updated AC box f3d files
    Added files for the six output AC box
    [AC Box Outlet Connector Insert.f3d, AC Box and Lid.f3d]
2026-08-05 Update Node-RED flows.json
    Up to date flows
2026-08-05 Rename RGB Box v1.f3d to RGB Box and Lid v1.f3d
    Update name
    [RGB Box and Lid v1.f3d]
2026-08-10 Enhance README with system flow and MQTT details
    Added a system explanation and details about the MQTT protocol and Node-RED configuration. Updated formatting and added missing sections.
2026-08-12 Add setup instructions to User Manual
    Added detailed setup instructions for the Hilliard Smart Christmas Lighting system, including steps for plugging in devices and using the app.
